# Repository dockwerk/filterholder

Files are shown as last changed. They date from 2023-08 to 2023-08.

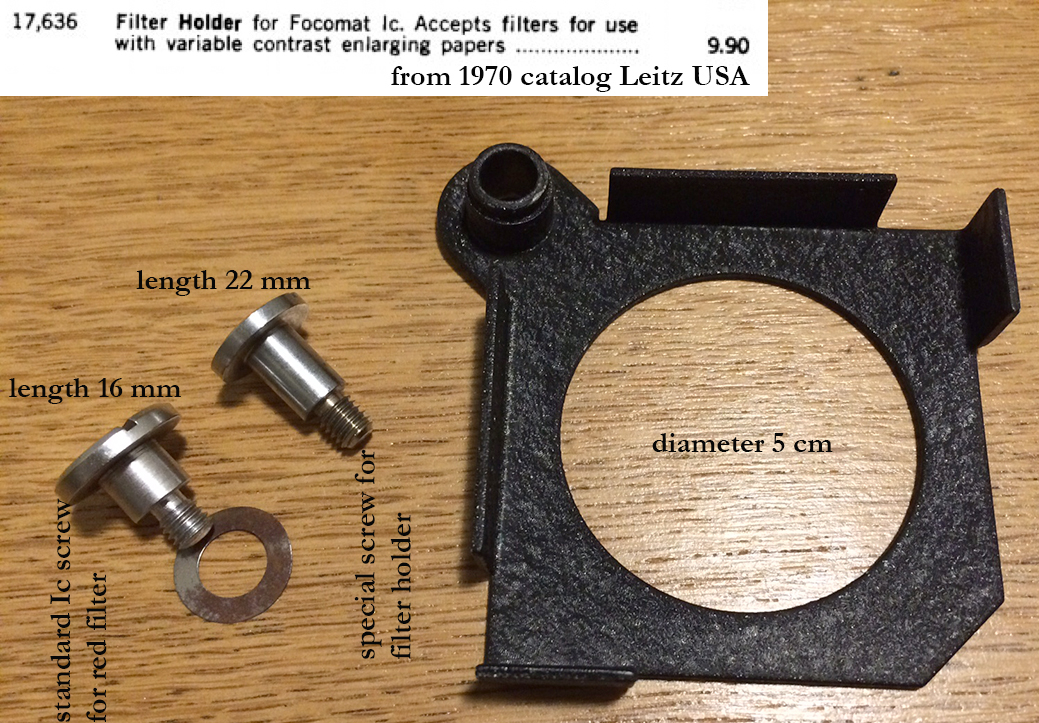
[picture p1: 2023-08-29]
17636/Leitz_filter_holder_with_special_shoulder_screw.jpg

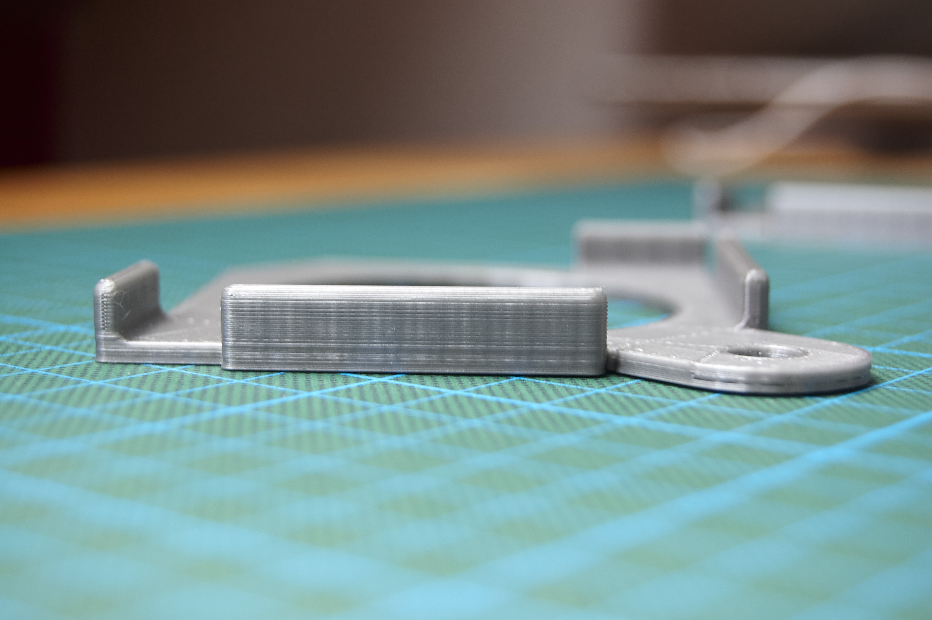
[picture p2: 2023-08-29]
prototypes/DSC_9280.jpg

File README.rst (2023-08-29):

***********************************************************
Filter-holders for Leitz Focomat Ic and Valloy II enlargers
***********************************************************

This project contains basic CAD drawings and specifications
to manufacture under the lens filter holders for the
following Leitz enlargers:

* Focomat Ic
* Valloy II

All filter holder designs are inspired by the hard to find
Leitz USA filter holder for Ic, part Nr. 17636 from the
1970 Leitz USA catalog. The stock red filter as well as
Beseler and Omega filter holders were used as inspiration
for a suitable design.

All rights reserved. At the moment this project is
proprietary. You may use the plans to make your own holder
for your private use. It is not allowed to sell holders
you make from this plans. 

A more liberal license will be determined soon.

We're looking for contributions:

  * Protoype manufacturing (laser milling) to verify designs
  * 3D drawing suitable for 3D milling

**Table of Contents**

.. contents::
    :local:
    :depth: 2
    :backlinks: none

=============================
Specifications for Focomat Ic
=============================

--------------
Main workpiece
--------------
Material:
  * Steel 1.5mm

Finish:
  * chrome plating, mat black (not: chromate conversion coating)
  * wrinkle paint, black (like 17636)

Mounting:
  * combination of a M6 shoulder with compression spring acting as
    distance sleeve and fixing position.

-------------------------------------
DIN 923 shoulder screw specifications
-------------------------------------
By choosing different lengths of the shoulder screw, various lens-holder
distances can be realized. The following specifications provide the closest
approximation to the 17636 holder.

+------------------------+----------+
| Thread                 | M6       |
+------------------------+----------+
| Diameter (head)        | 13mm     |
+------------------------+----------+
| Diameter (shoulder)    | 8mm      |
+------------------------+----------+
| Length (shoulder)      | 10mm     |
+------------------------+----------+
| Length (thread)        | 9mm      |
+------------------------+----------+

---------------------------------
Compression spring specifications
---------------------------------

+------------------------+----------------------+
| Type                   | compression, V2A     |
+------------------------+----------------------+
| Ends                   | angelegt+geschliffen |
+------------------------+----------------------+
| Wire diameter          | 1mm                  |
+------------------------+----------------------+
| Spine diameter         | 8mm                  |
+------------------------+----------------------+
| Mininum length         | 10mm                 |
+------------------------+----------------------+
| Maximum length         | tbd                  |
+------------------------+----------------------+
| Nominal length         | tbd                  |
+------------------------+----------------------+

We ordered the following product to experiment
with: Gutekunst `VD-151B`_ and finialize the specifications.

===========================
Specifications for Valoy II
===========================

This holder differs only in the use of a slotted hole instead of a
round one. Therefore the holder can be mounted on the adjustable
L-bracket which comes with the red filter of the Valoy II.

==========================================
Specification of the original 17636 holder
==========================================

All specs are measured with common tools and might not be 100% accurate.

Shoulder screw:

+------------------------+-----------------------+
| Typ                    | Flachkopf mit Schlitz |
+------------------------+-----------------------+
| Gewinde                | M6                    |
+------------------------+-----------------------+
| Durchmesser Kopf       | 15mm                  |
+------------------------+-----------------------+
| Durchmesser Bund       | 8mm (little less)     |
+------------------------+-----------------------+
| Länge Bund             | 11mm                  |
+------------------------+-----------------------+
| Länge Gewinde          | 7mm                   |
+------------------------+-----------------------+

================
Acknowledgements
================

Software used for the CAD drawings: `QCAD`_

.. _QCAD: https://qcad.org
.. _VD-151B: https://www.federnshop.com/de/datenblatt/gk-federnshop_druckfedern_vd-151b.pdf

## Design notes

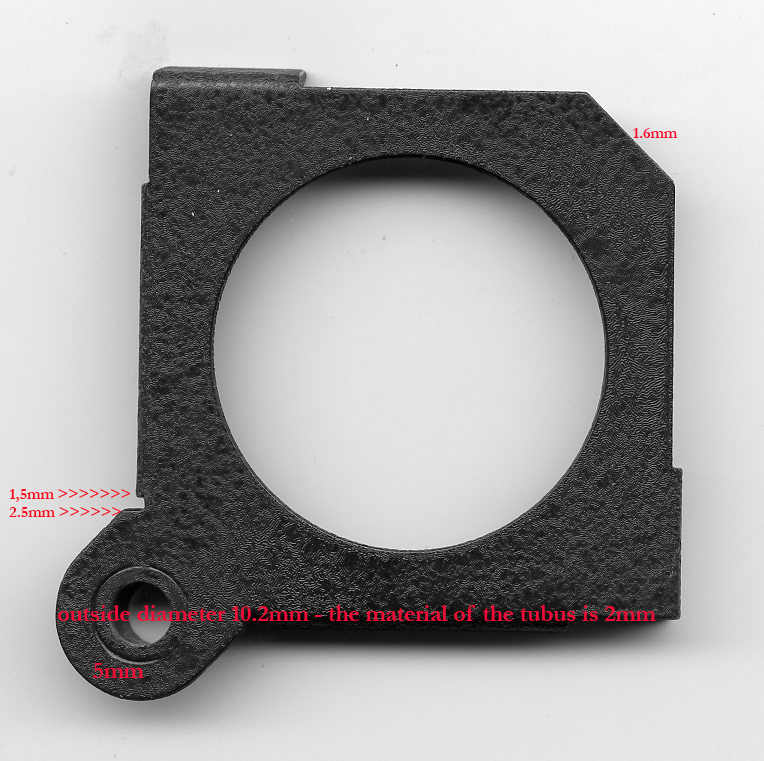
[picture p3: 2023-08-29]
17636/holder_01-1.jpg

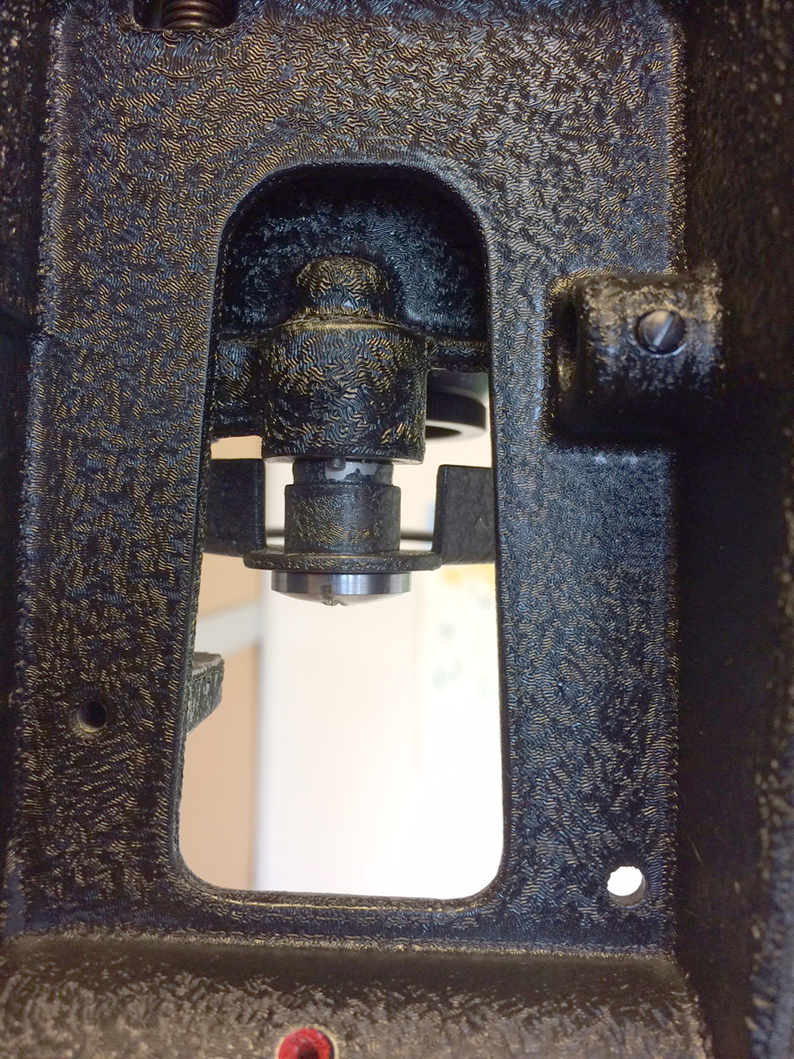
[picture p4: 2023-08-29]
17636/holder_seen_from_behind.jpg

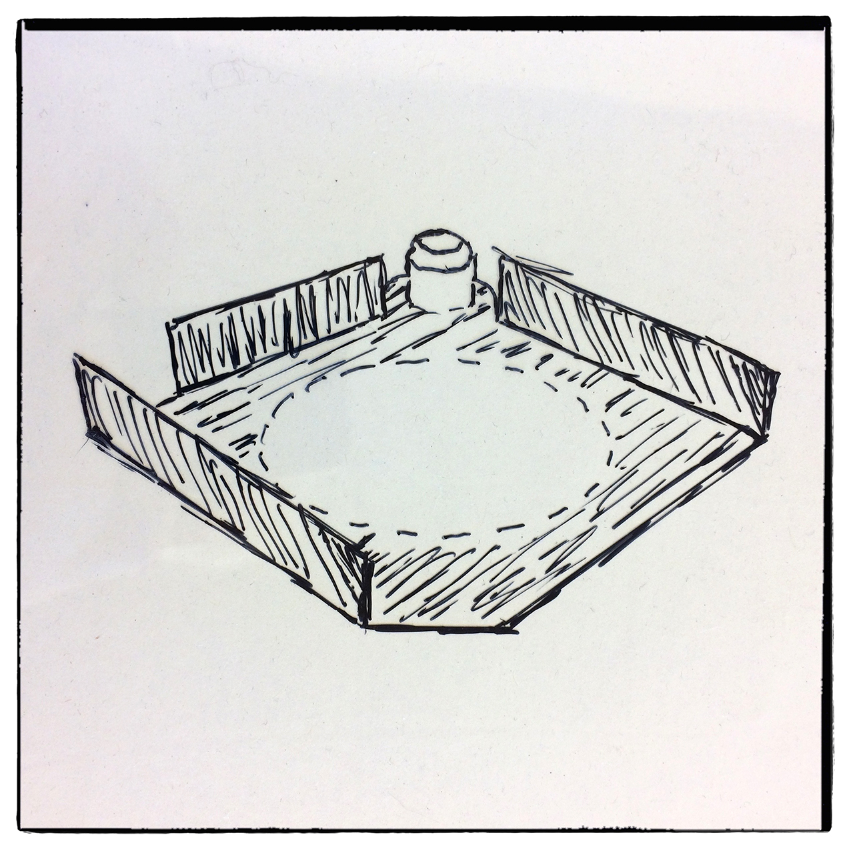
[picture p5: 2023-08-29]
alternatives/sketch_02.jpg

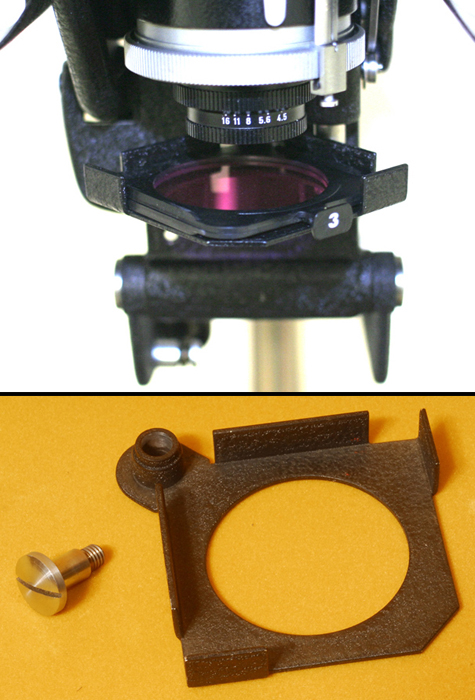
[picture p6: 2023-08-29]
17636/leitz_holder.jpg

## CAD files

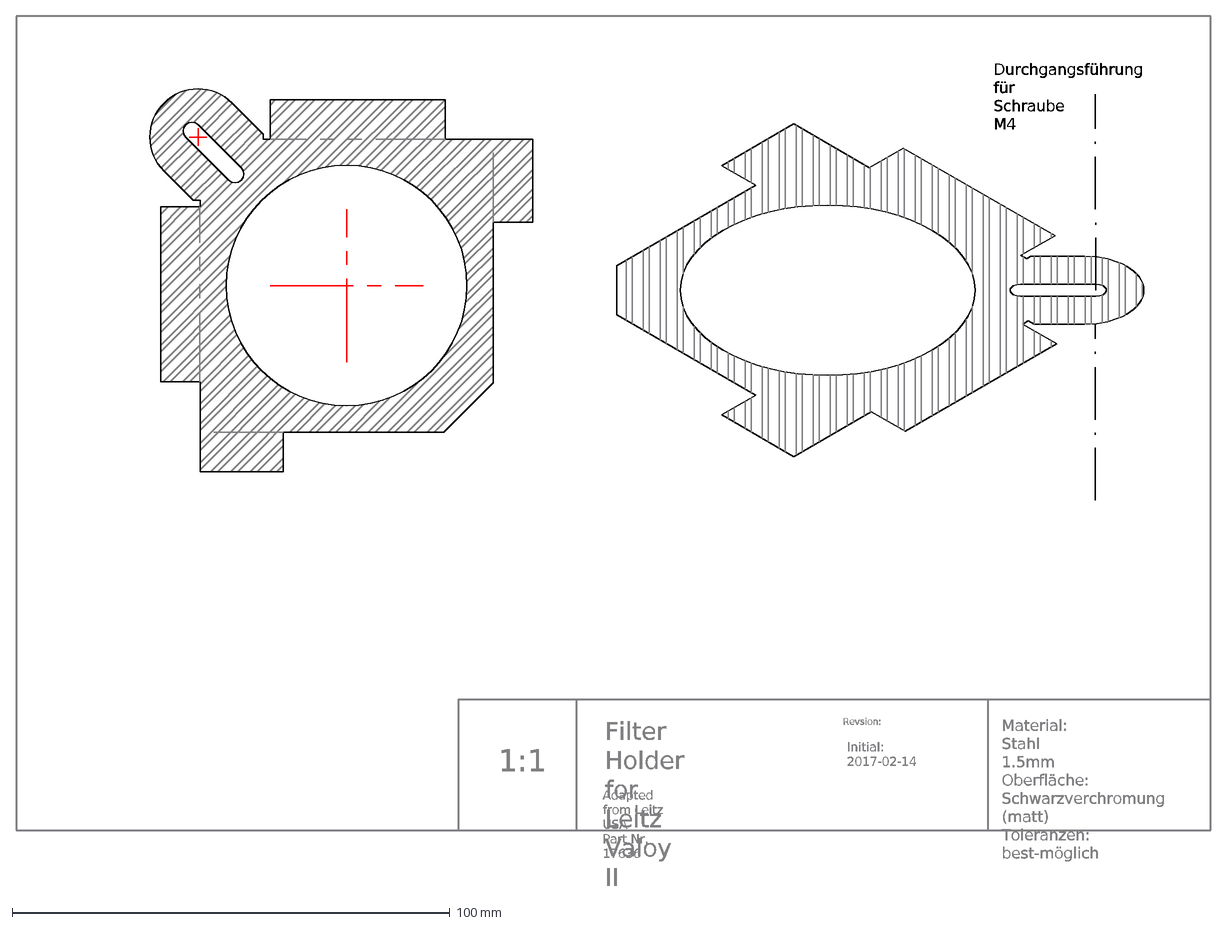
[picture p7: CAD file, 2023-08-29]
leitz_valloyII_filter_holder.dxf
Filter Holder for Leitz Valoy II
Material: Stahl 1.5mm Oberfläche: Schwarzverchromung (matt) Toleranzen: best-möglich
1:1
Adapted from Leitz USA Part Nr. 17636
Revsion:
Initial: 2017-02-14
Durchgangsführung für Schraube M4

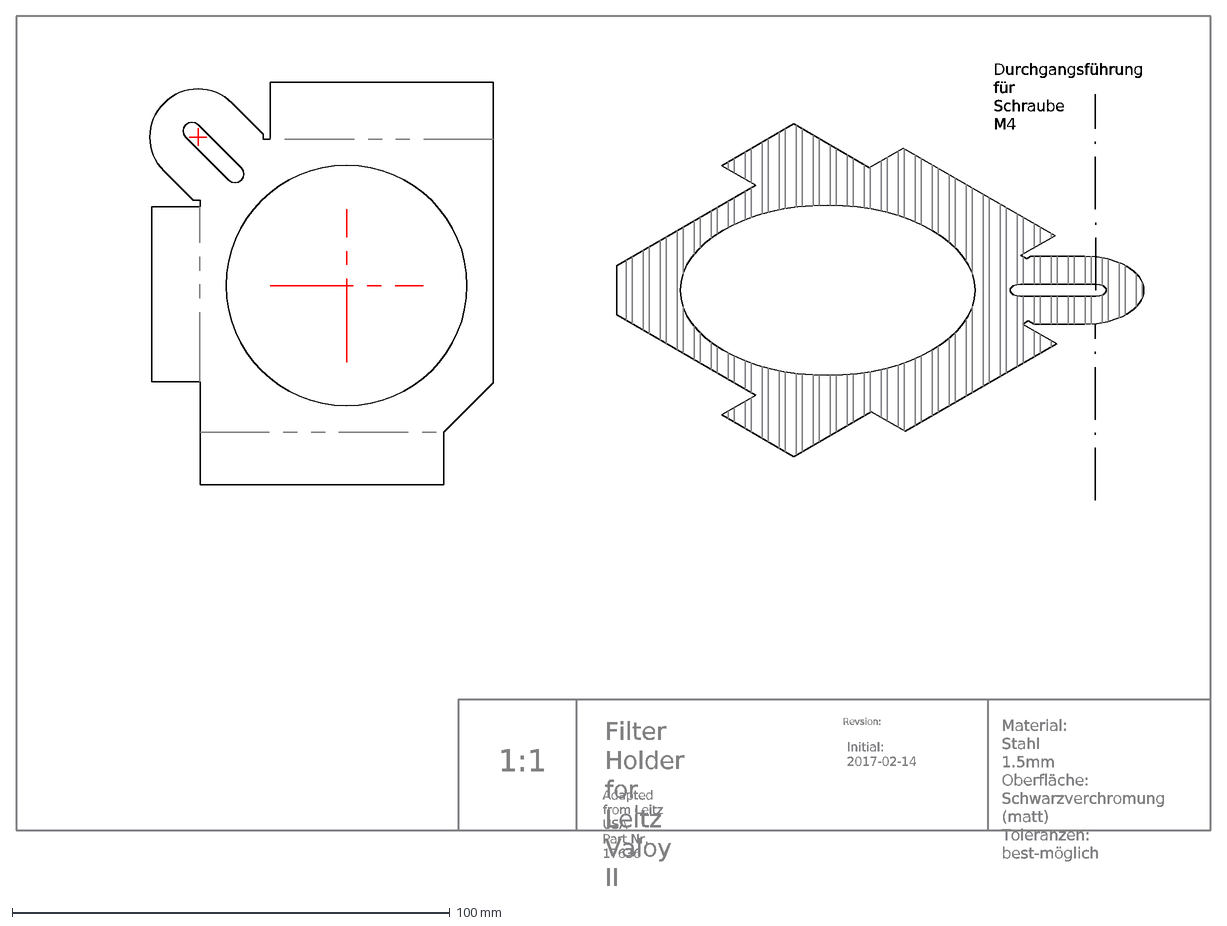
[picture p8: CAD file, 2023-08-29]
leitz_valloyII_filter_holder_alternative.dxf
Filter Holder for Leitz Valoy II
Material: Stahl 1.5mm Oberfläche: Schwarzverchromung (matt) Toleranzen: best-möglich
1:1
Adapted from Leitz USA Part Nr. 17636
Revsion:
Initial: 2017-02-14
Durchgangsführung für Schraube M4

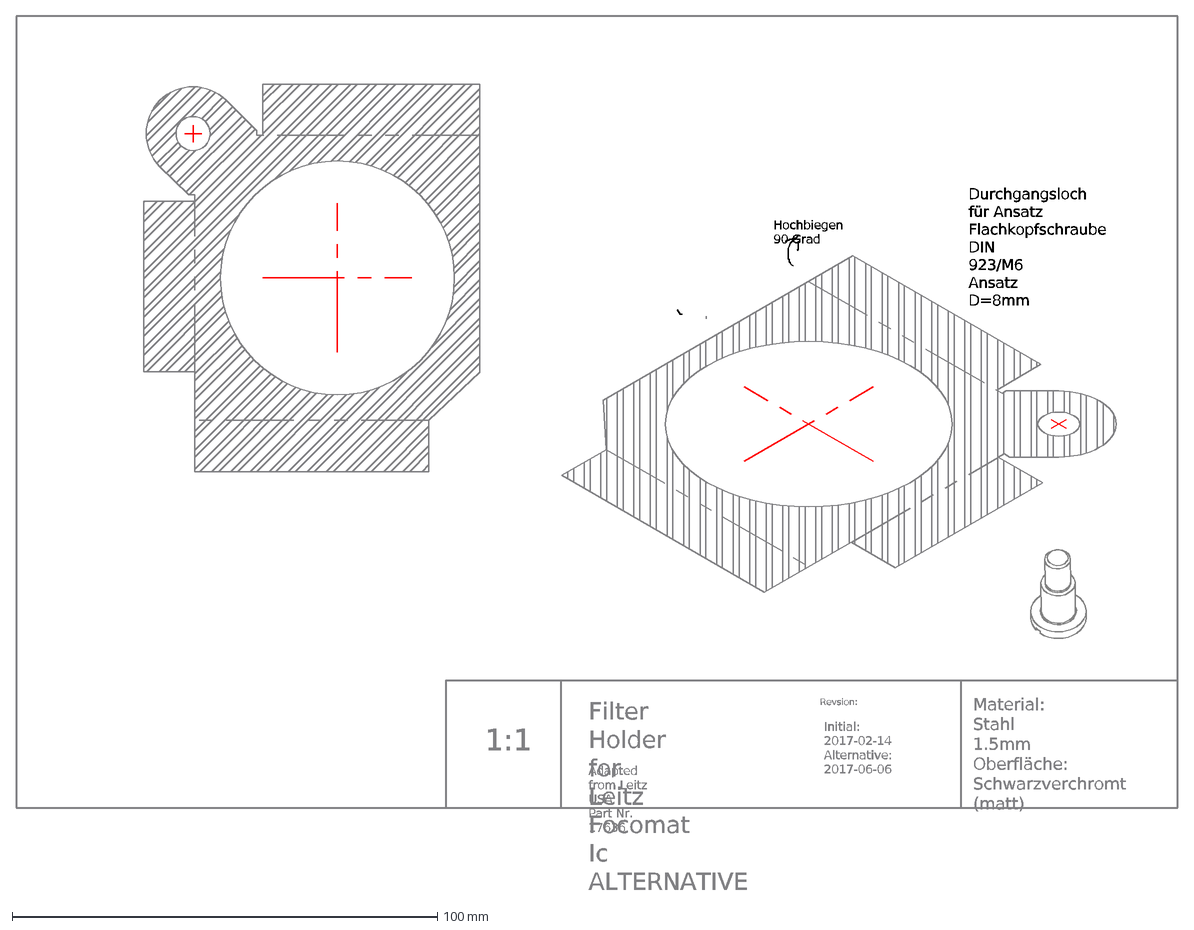
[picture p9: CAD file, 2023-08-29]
leitz_1c_filter_holder_alternative.dxf
Filter Holder for Leitz Focomat Ic ALTERNATIVE
Material: Stahl 1.5mm Oberfläche: Schwarzverchromt (matt)
1:1
Adapted from Leitz USA Part Nr. 17636
Revsion:
Initial: 2017-02-14 Alternative: 2017-06-06
Durchgangsloch für Ansatz Flachkopfschraube DIN 923/M6 Ansatz D=8mm
Hochbiegen 90 Grad

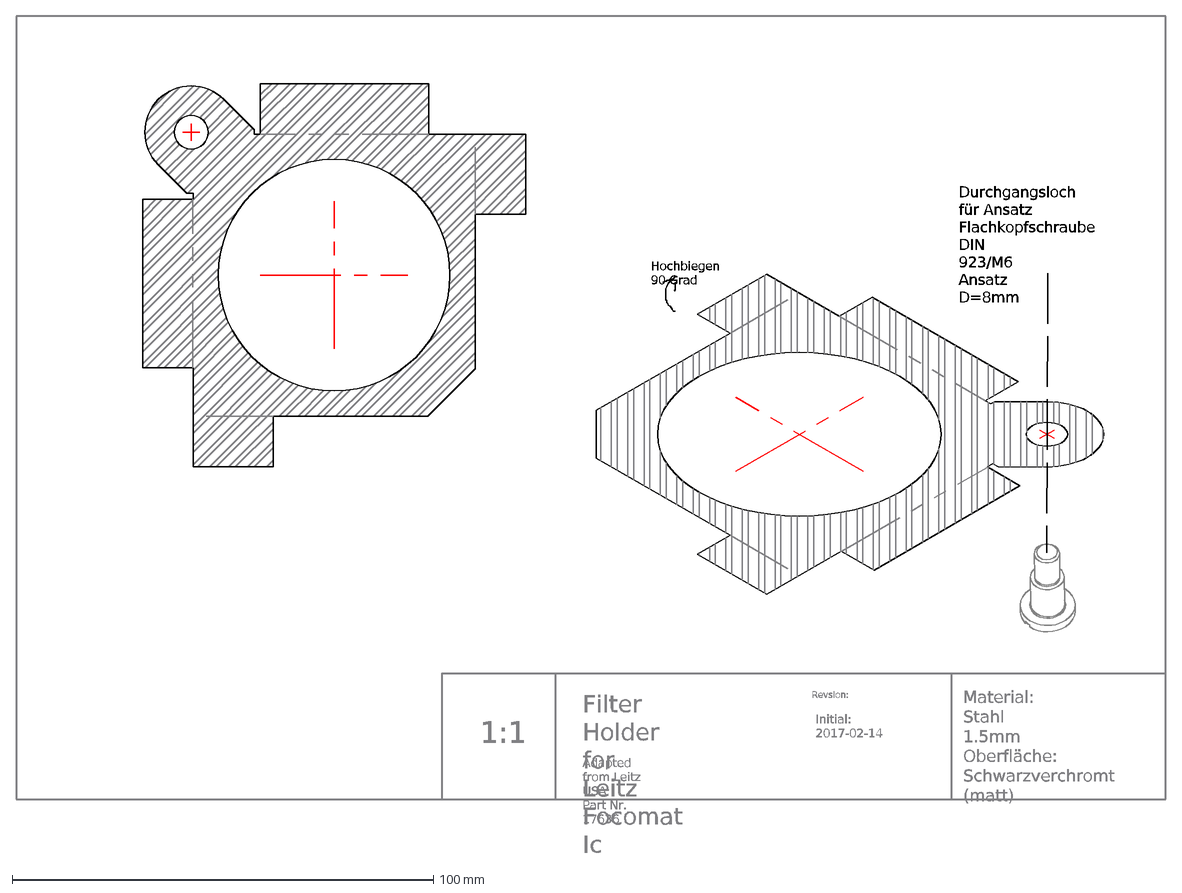
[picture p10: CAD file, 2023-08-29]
leitz_1c_filter_holder.dxf
Filter Holder for Leitz Focomat Ic
Material: Stahl 1.5mm Oberfläche: Schwarzverchromt (matt)
1:1
Adapted from Leitz USA Part Nr. 17636
Revsion:
Initial: 2017-02-14
Durchgangsloch für Ansatz Flachkopfschraube DIN 923/M6 Ansatz D=8mm
Hochbiegen 90 Grad

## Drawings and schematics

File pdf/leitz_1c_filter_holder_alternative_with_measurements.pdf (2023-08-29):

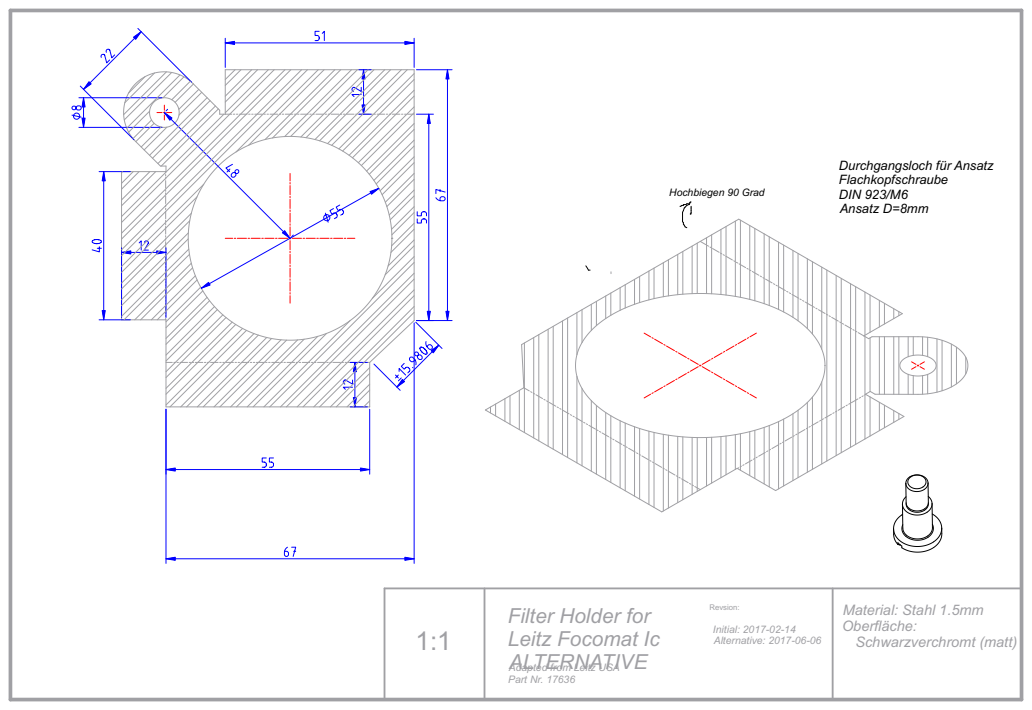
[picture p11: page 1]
Material: Stahl 1.5mm; Oberfläche: 1:1; Schwarzverchromt (matt); Revsion:; Initial: 2017-02-14 Alternative: 2017-06-06; Hochbiegen 90 Grad

Durchgangsloch für Ansatz
Flachkopfschraube
DIN 923/M6
Ansatz D=8mm

Filter Holder for
Leitz Focomat Ic
ALTERNATIVE
Adapted from Leitz USA
Part Nr. 17636

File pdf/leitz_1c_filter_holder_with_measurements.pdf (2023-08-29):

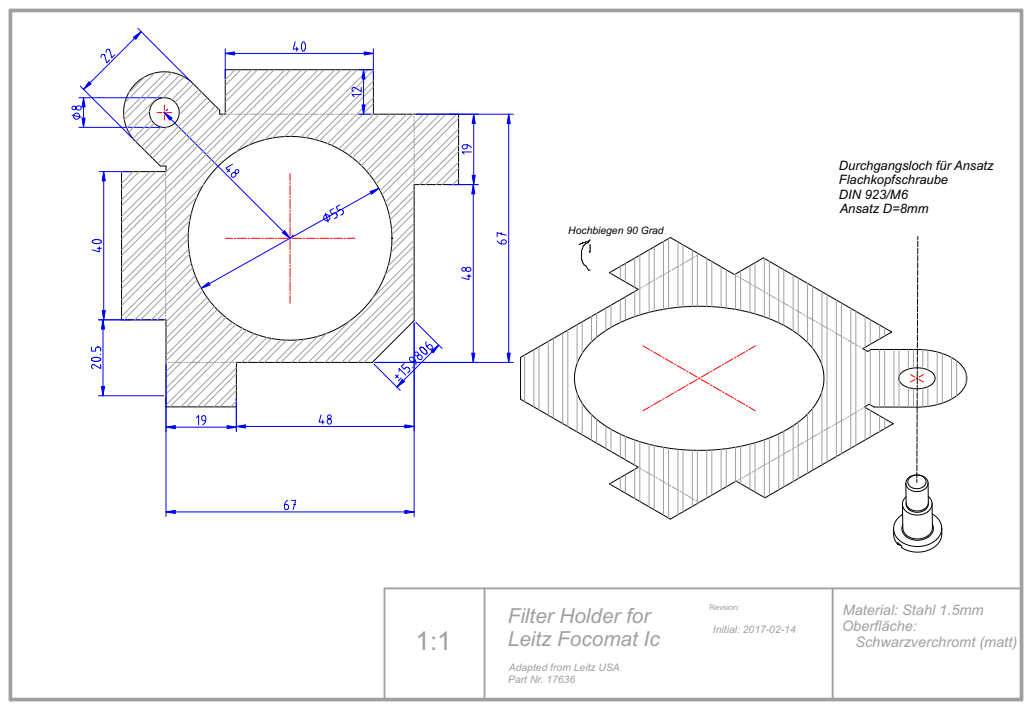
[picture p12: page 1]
Material: Stahl 1.5mm; Oberfläche: 1:1; Schwarzverchromt (matt); Revsion:; Initial: 2017-02-14; Hochbiegen 90 Grad

Durchgangsloch für Ansatz
Flachkopfschraube
DIN 923/M6
Ansatz D=8mm

Filter Holder for
Leitz Focomat Ic

Adapted from Leitz USA
Part Nr. 17636

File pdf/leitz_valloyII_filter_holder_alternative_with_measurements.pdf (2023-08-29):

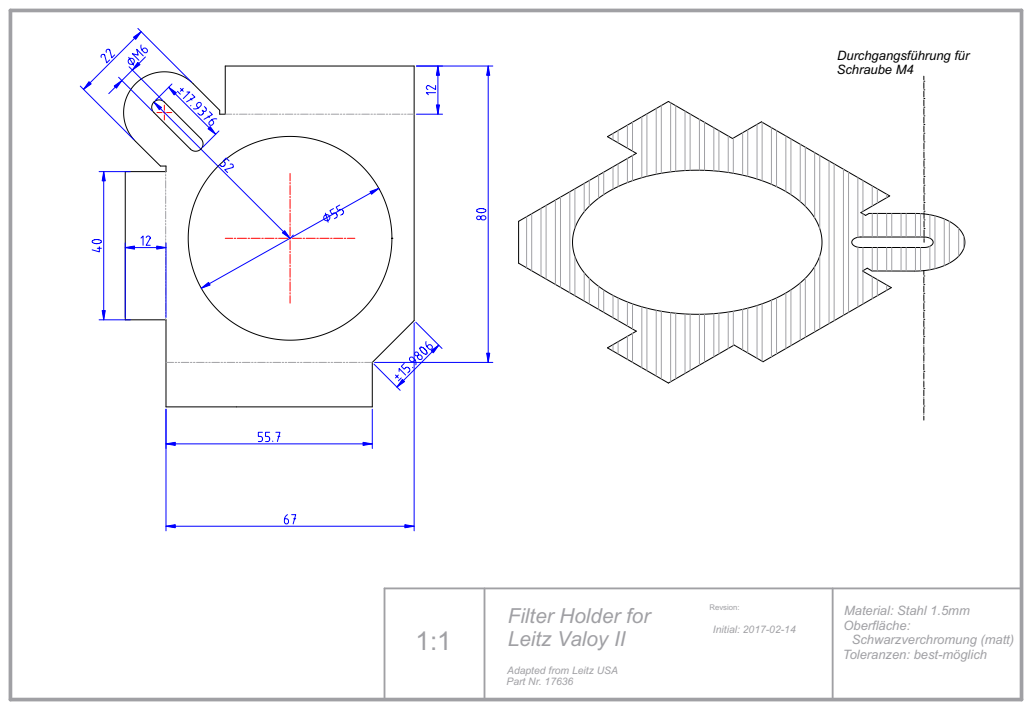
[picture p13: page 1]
Revsion:; Initial: 2017-02-14; Durchgangsführung für Schraube M4

Filter Holder for
Leitz Valoy II

Material: Stahl 1.5mm
Oberfläche:
Schwarzverchromung (matt)
Toleranzen: best-möglich

Adapted from Leitz USA
Part Nr. 17636
